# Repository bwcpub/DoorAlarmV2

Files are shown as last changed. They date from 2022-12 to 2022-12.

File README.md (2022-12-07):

# DoorAlarmV2

## A newer, hopefully better, version of the Door Alarm board.

**(C) 2022 Ben Cantrick. These files are distributed under a Creative Commons Attribution-ShareAlike license, see LICENSE_CCBYSA40.TXT.**

A newer, hopefully better, version of the Door Alarm board. Now fully compliant with the "just use a 555 timer" meme!

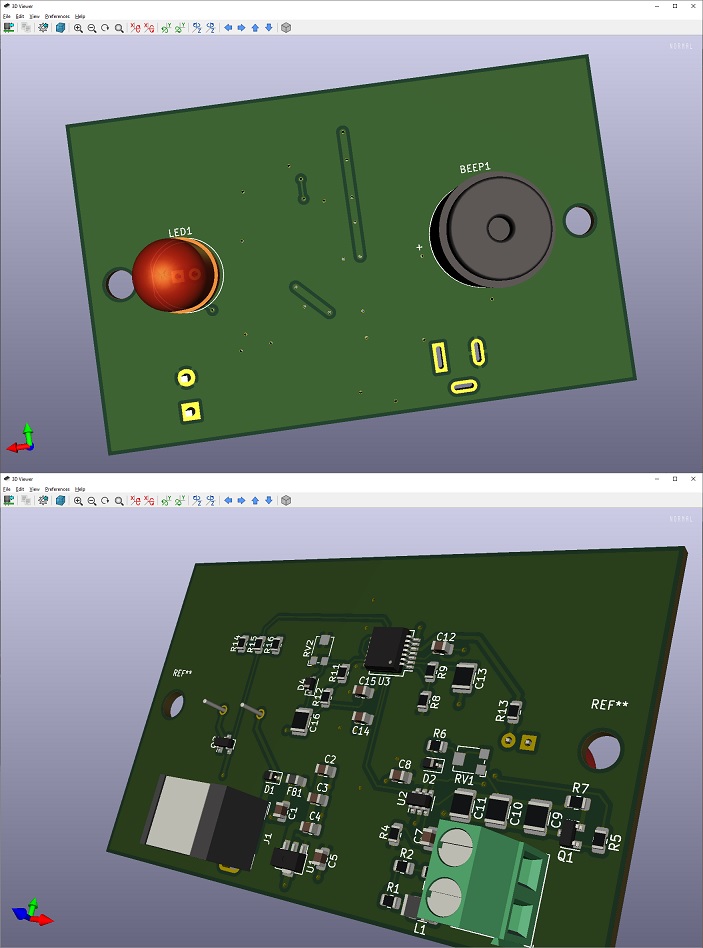
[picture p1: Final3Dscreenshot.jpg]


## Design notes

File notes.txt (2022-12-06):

Fits in a single gang electrical box.
Nominal width: 2 in = 50.8mm
Nominal height: 4 in = 101.6mm (see below)
Nominal depth: 1 7/8 in = 1.875 in = 47.625mm

Two inside flanges for attaching top plate reduce height by ~10mm each, so usable height more like 80mm.

PCB size target: 80mm x 50mm

-----

Simulation: See "falstadsim circuit.txt"

-----

https://www.digikey.com/en/products/detail/taiyo-yuden/LMK325B7476KM-PR/5810977

47 uF X7R 10V 1210 ceramic cap, 3 in parallel for 141 uF (+ 562k 1% resistor = 61s to charge from 0 to 2.7V from a 5V regulated source)
Manuf renamed part to MSASL32MSB7476KPNB25_RS sometime in late 2021.
Manuf data sheet claims 100MOhm per uF for insulation resistance. That would make parallel of three = 4.7 GOhm / 3 = ~1.56 GOhm.

-----

Dual schmitt buffer, $0.33 @10 (not in-stock at Digikey)
Mouser # 595-SN74LVC2G17DBVT

32 mA max output drive at Vcc=4.5V  (full device limited to 50mA total, so keep each output to ~20mA)

Data sheet says bypass with 0.1 uF cap as close as possible to VCC. (Multiple parallel caps OK if desired.)

TI "DBV00006A" package legs are nearly identical to SOT-23-6 footprint. (Case is very slightly larger.)

-------

10mm Red LED
https://www.mouser.com/ProductDetail/Kingbright/WP813SRD-E?qs=58z0TXQGVSToOd55Z46ELQ%3D%3D

-----

Buzzer - nice balance of cost vs loudness. $2.80 @10
https://www.digikey.com/en/products/detail/cui-devices/CMI-1614C-120/6012412

556 timer 
https://www.digikey.com/en/products/detail/texas-instruments/NE556DBR/1571972

PNP
https://www.digikey.com/en/products/detail/diodes-incorporated/MMBT3906-7-F/770797

-----

10k trim pot for beep duration - https://www.digikey.com/en/products/detail/bourns-inc/TC33X-2-103E/612858

500k trim pot for door open to alarm delay - https://www.digikey.com/en/products/detail/bourns-inc/TC33X-2-504E/2566902

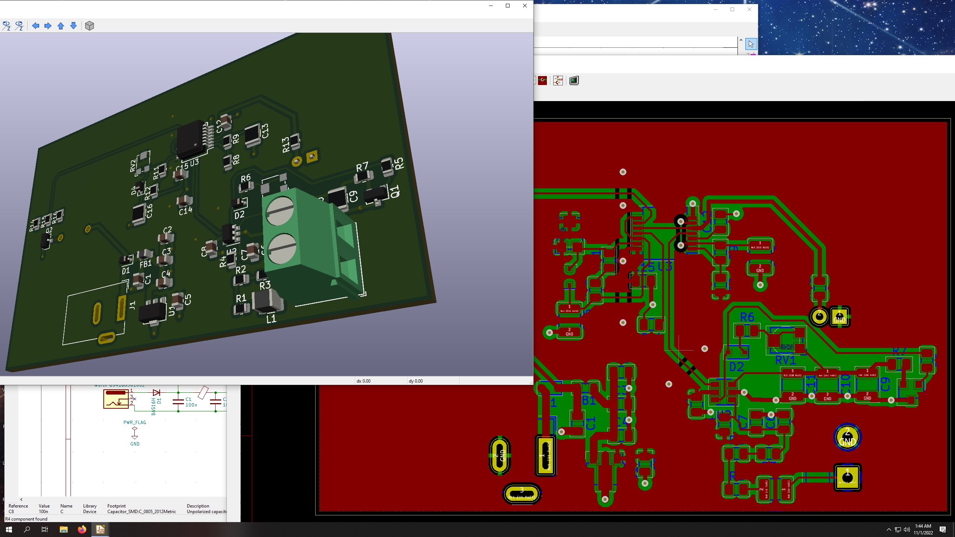
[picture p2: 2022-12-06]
WIPscreenshot.jpg

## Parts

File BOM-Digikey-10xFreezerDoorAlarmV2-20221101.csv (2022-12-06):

Country of Origin may be different at time of shipment.
The HTSUS and ECCN information shown is for informational purposes only and is not a representation or warranty as to the accuracy or reliability of these classifications. All information is provided "as is" and is subject to change without notice. Any use made of the information provided is without recourse to Digi-Key and at the user's risk.
Index | Manufacturer Part Number | Manufacturer Name | Description | Availability | Stock Status | Attrition % | Requested Quantity 1 | Pack Quantity 1 | Pack Type 1 | Digi-Key Part Number 1 | Unit Price 1 | Extended Price 1 | Minimum Order Quantity 1 | Customer Reference | Requested Part Number | Lead Weeks | Datasheet | Reference Designator | US Import Tariff | Note | Part Status | RoHS Status | ECCN | HTSUS | Country of Origin | Environmental Information | Original Part numbers | Image
1 | CMI-1614C-120 | CUI Devices | BUZZER MAGNETIC 12V 16MM TH | 239 | In Stock |  | 10 | 10 | Tray | 102-3741-ND | 2.79100 | $27.91 | 1 |  | 102-3741-ND | 8 | https://www.cuidevices.com/product/resource/cmi-1614c-120.pdf |  | May apply on shipments to the U.S. |  | Active | ROHS3 Compliant | EAR99 | 8531.80.9041 | China | https://www.cuidevices.com/product/resource/material-compliance/cmi-1614c-120 | 102-3741-ND | https://media.digikey.com/photos/CUI%20Photos/MFG_CMI-1614C-120.jpg
2 | 1729128 | Phoenix Contact | TERM BLK 2P SIDE ENT 5.08MM PCB | 39,675 | In Stock |  | 10 | 10 | Bulk | 277-1247-ND | 1.16200 | $11.62 | 1 |  | 277-1247-ND | 21 | https://www.phoenixcontact.com/product/pdf/MTcyOTEyOA?_realm=us&_locale=en-US |  | May apply on shipments to the U.S. |  | Active | ROHS3 Compliant | EAR99 | 8536.69.4040 | China | https://www.phoenixcontact.com/online/portal/us?1dmy | 277-1247-ND | https://media.digikey.com/photos/Phoenix%20Photos/1729128.jpg
3 | 694106301002 | Würth Elektronik | CONN PWR JACK 2.1X5.5MM SOLDER | 40,477 | In Stock |  | 10 | 10 | Bag | 732-5930-ND | 0.97000 | $9.70 | 1 |  | 732-5930-ND | 15 | https://www.we-online.com/katalog/datasheet/6941xx301002.pdf |  | May apply on shipments to the U.S. |  | Active | ROHS3 Compliant | EAR99 | 8536.69.4040 | China | https://media.digikey.com/pdf/Other%20Related%20Documents/Wurth/Certificate_of_Compliance_ROHS.pdf | 732-5930-ND | https://media.digikey.com/Photos/Wurth%20Electronics%20Photos/MFG_694106x0x002.jpg
4 | WLBD2012HCU601TH | Walsin Technology Corporation | CHIP BEAD 600 OHM 0805 | 2,823 | In Stock |  | 10 | 10 | Cut Tape (CT) | 1292-WLBD2012HCU601THCT-ND | 0.02800 | $0.28 | 1 |  | 1292-WLBD2012HCU601THCT-ND | 30 | http://www.passivecomponent.com/wp-content/uploads/inductor/WLBD1005-4532_HC_Series.pdf |  | - |  | Active | ROHS3 Compliant | EAR99 | 8548.00.0000 | Taiwan | http://www.passivecomponent.com/download/reach_rohs_compliance_declaration-2/?wpdmdl=1343 | 1292-WLBD2012HCU601THCT-ND | https://media.digikey.com/Renders/Walsin%20Tech/WLBD2012x.JPG
5 | NE556DBR | Texas Instruments | IC OSC TIMER DUAL 100KHZ 14SSOP | 505 | In Stock |  | 10 | 10 | Cut Tape (CT) | 296-31698-1-ND | 0.49700 | $4.97 | 1 |  | 296-31698-1-ND | 6 | https://www.ti.com/general/docs/suppproductinfo.tsp?distId=10 |  | - |  | Active | ROHS3 Compliant | EAR99 | 8542.39.0001 | Malaysia |  | 296-31698-1-ND | https://media.digikey.com/photos/Texas%20Instr%20Photos/296-14-SSOP.jpg
6 | AS78L05RTR-E1 | Diodes Incorporated | IC REG LINEAR 5V 100MA SOT89-3 | 220,818 | In Stock |  | 10 | 10 | Cut Tape (CT) | AS78L05RTR-E1DICT-ND | 0.30600 | $3.06 | 1 |  | AS78L05RTR-E1DICT-ND | 27 | https://media.digikey.com/pdf/Data%20Sheets/Diodes%20PDFs/AS78Lxx_Aug2013_DS.pdf |  | May apply on shipments to the U.S. |  | Active | ROHS3 Compliant | EAR99 | 8542.39.0001 | China | https://www.diodes.com/assets/Quality-Reliability-Docs/Master_CofC.pdf | AS78L05RTR-E1DICT-ND | https://media.digikey.com/Renders/Diodes%20Renders/SOT89-3L.jpg
7 | TC33X-2-103E | Bourns Inc. | TRIMMER 10K OHM 0.1W J LEAD TOP | 113,212 | In Stock |  | 10 | 10 | Cut Tape (CT) | TC33X-103ECT-ND | 0.27300 | $2.73 | 1 |  | TC33X-103ECT-ND | 32 | https://www.bourns.com/docs/Product-Datasheets/TC33.pdf |  | May apply on shipments to the U.S. |  | Active | ROHS3 Compliant | EAR99 | 8533.40.8050 | China | https://www.bourns.com/docs/rohs-cofc/cofc_trim2.pdf?sfvrsn=d03d9c0f_4|https://www.bourns.com/docs/rohs-content/bourns-reach-letter.pdf | TC33X-103ECT-ND | https://media.digikey.com/photos/Bourns%20Photos/TC33X%20SERIES.jpg
8 | TC33X-2-504E | Bourns Inc. | TRIMMER 500K OHM 0.1W J LEAD TOP | 3,746 | In Stock |  | 10 | 10 | Cut Tape (CT) | TC33X-2-504ECT-ND | 0.27300 | $2.73 | 1 |  | TC33X-2-504ECT-ND | 32 | https://www.bourns.com/docs/Product-Datasheets/TC33.pdf |  | May apply on shipments to the U.S. |  | Active | ROHS3 Compliant | EAR99 | 8533.40.8050 | China | https://www.bourns.com/docs/rohs-content/bourns-reach-letter.pdf|https://www.bourns.com/docs/rohs-cofc/cofc_trim2.pdf?sfvrsn=d03d9c0f_4 | TC33X-2-504ECT-ND | https://media.digikey.com/photos/Bourns%20Photos/TC33X%20SERIES.jpg
9 | NVTR4503NT1G | onsemi | MOSFET N-CH 30V 1.5A SOT23-3 | 11,318 | In Stock |  | 10 | 10 | Cut Tape (CT) | NVTR4503NT1GOSCT-ND | 0.30600 | $3.06 | 1 |  | NVTR4503NT1GOSCT-ND | 48 | https://www.onsemi.com/pdf/datasheet/ntr4503n-d.pdf |  | May apply on shipments to the U.S. |  | Active | ROHS3 Compliant | EAR99 | 8541.21.0095 | China | https://www.onsemi.com/site/pdf/RoHS-statement.pdf|https://www.onsemi.com/PowerSolutions/MaterialComposition.do?export=pdf&opnId=NVTR4503NT1G|https://www.onsemi.com/site/pdf/REACH-compliance-statement.pdf | NVTR4503NT1GOSCT-ND | https://media.digikey.com/Renders/On%20Semi%20Renders/SOT-23-3,TO-236-3,Micro3,SSD3,SST3.jpg
10 | MMBT3906-7-F | Diodes Incorporated | TRANS PNP 40V 0.2A SOT23-3 | 463,784 | In Stock |  | 10 | 10 | Cut Tape (CT) | MMBT3906-FDICT-ND | 0.11700 | $1.17 | 1 |  | MMBT3906-FDICT-ND | 26 | https://media.digikey.com/pdf/Data%20Sheets/Diodes%20PDFs/MMBT3906.pdf |  | May apply on shipments to the U.S. |  | Active | ROHS3 Compliant | EAR99 | 8541.21.0075 | China | https://www.diodes.com/assets/Quality-Reliability-Docs/Master_CofC.pdf | MMBT3906-FDICT-ND | https://media.digikey.com/Photos/Diodes%20Photos/SOT-23-3%20PKG.jpg
11 | BAS16HT3G | onsemi | DIODE GEN PURP 100V 200MA SOD323 | 78,000 | In Stock |  | 30 | 30 | Cut Tape (CT) | BAS16HT3GOSCT-ND | 0.11700 | $3.51 | 1 |  | BAS16HT3GOSCT-ND | 59 | https://www.onsemi.com/pdf/datasheet/bas16ht1-d.pdf |  | May apply on shipments to the U.S. |  | Active | ROHS3 Compliant | EAR99 | 8541.10.0070 | China | https://www.onsemi.com/site/pdf/RoHS-statement.pdf|https://www.onsemi.com/PowerSolutions/MaterialComposition.do?export=pdf&opnId=BAS16HT3G|https://www.onsemi.com/site/pdf/REACH-compliance-statement.pdf | BAS16HT3GOSCT-ND | https://media.digikey.com/Renders/On%20Semi%20Renders/SOD-323_477.jpg
12 | LB3218T102K | Taiyo Yuden | FIXED IND 1MH 39MA 27 OHM SMD | 86,463 | In Stock |  | 10 | 10 | Cut Tape (CT) | 587-2041-1-ND | 0.14600 | $1.46 | 1 |  | 587-2041-1-ND | 35 | https://ds.yuden.co.jp/TYCOMPAS/ut/detail?pn=LB3218T102K &u=M |  | - |  | Active | ROHS3 Compliant | EAR99 | 8504.50.8000 | Philippines |  | 587-2041-1-ND | https://media.digikey.com/Photos/Taiyo%20Yuden%20Photos/MFG_LB3218T681KV.jpg
13 | LMK325B7476KM-PR | Taiyo Yuden | CAP CER 47UF 10V X7R 1210 | 94,515 | In Stock |  | 50 | 50 | Cut Tape (CT) | 587-5921-1-ND | 0.52240 | $26.12 | 1 |  | 587-5921-1-ND | 56 | https://www.yuden.co.jp/productdata/catalog/mlcc06_e.pdf |  | - |  | Active | ROHS3 Compliant | EAR99 | 8532.24.0020 | South Korea |  | 587-5921-1-ND | https://media.digikey.com/Renders/Taiyo%20Yuden%20Renders/1210-(3225-Metric)-2,70mm.jpg
14 | CL21B104MACNNNC | Samsung Electro-Mechanics | CAP CER 0.1UF 25V X7R 0805 | 503,335 | In Stock |  | 100 | 100 | Cut Tape (CT) | 1276-2449-1-ND | 0.01240 | $1.24 | 1 |  | 1276-2449-1-ND | 22 | http://www.samsungsem.com/kr/support/product-search/mlcc/CL21B104MACNNNC.jsp |  | - |  | Active | ROHS3 Compliant | EAR99 | 8532.24.0020 | China | https://www.samsungsem.com/global/support/certificate/product-stewardship.do|https://www.samsungsem.com/files/fileDown.do?key=ed1dfdfa-645e-4252-b707-17f9b1502dd1 | 1276-2449-1-ND | https://media.digikey.com/Renders/Samsung%20Electro-Mechanics%20America/Ceramic-Capacitor-CL-Series.jpg
15 | RMCF0805FT62K0 | Stackpole Electronics Inc | RES 62K OHM 1% 1/8W 0805 | 58,468 | In Stock |  | 10 | 10 | Cut Tape (CT) | RMCF0805FT62K0CT-ND | 0.02400 | $0.24 | 1 |  | RMCF0805FT62K0CT-ND | 15 | https://www.seielect.com/catalog/sei-rmcf_rmcp.pdf |  | May apply on shipments to the U.S. |  | Active | ROHS3 Compliant | EAR99 | 8533.21.0030 | Taiwan | https://www.seielect.com/catalog/reach.pdf|https://www.seielect.com/catalog/cert-of-compliance.pdf|https://www.seielect.com/catalog/SEI-RoHS_Compliance_Status.pdf | RMCF0805FT62K0CT-ND | https://media.digikey.com/Renders/Stackpole%20Renders/0805-RMCF-Series.jpg
16 | WR08X153 JTL | Walsin Technology Corporation | RES 15K OHM 5% 1/8W 0805 | 11,101 | In Stock |  | 20 | 20 | Cut Tape (CT) | 1292-WR08X153JTLCT-ND | 0.01500 | $0.30 | 1 |  | 1292-WR08X153JTLCT-ND | 26 | http://www.passivecomponent.com/wp-content/uploads/chipR/ASC_WR.pdf |  | May apply on shipments to the U.S. |  | Active | ROHS3 Compliant | EAR99 | 8533.21.0030 | China | http://www.passivecomponent.com/download/reach_rohs_compliance_declaration-2/?wpdmdl=1343 | 1292-WR08X153JTLCT-ND | https://media.digikey.com/Renders/Stackpole%20Renders/0201-RMCF-Series.jpg
17 | RMCF0805JT8K20 | Stackpole Electronics Inc | RES 8.2K OHM 5% 1/8W 0805 | 128,993 | In Stock |  | 10 | 10 | Cut Tape (CT) | RMCF0805JT8K20CT-ND | 0.01800 | $0.18 | 1 |  | RMCF0805JT8K20CT-ND | 15 | https://www.seielect.com/catalog/sei-rmcf_rmcp.pdf |  | - |  | Active | ROHS3 Compliant | EAR99 | 8533.21.0030 | China | https://www.seielect.com/catalog/cert-of-compliance.pdf|https://www.seielect.com/catalog/SEI-RoHS_Compliance_Status.pdf|https://www.seielect.com/catalog/reach.pdf | RMCF0805JT8K20CT-ND | https://media.digikey.com/Renders/Stackpole%20Renders/0805-RMCF-Series.jpg
18 | RMCF0805FT1K00 | Stackpole Electronics Inc | RES 1K OHM 1% 1/8W 0805 | 3,216,460 | In Stock |  | 30 | 30 | Cut Tape (CT) | RMCF0805FT1K00CT-ND | 0.02400 | $0.72 | 1 |  | RMCF0805FT1K00CT-ND | 15 | https://www.seielect.com/catalog/sei-rmcf_rmcp.pdf |  | May apply on shipments to the U.S. |  | Active | ROHS3 Compliant | EAR99 | 8533.21.0030 | China | https://www.seielect.com/catalog/reach.pdf|https://www.seielect.com/catalog/SEI-RoHS_Compliance_Status.pdf|https://www.seielect.com/catalog/cert-of-compliance.pdf | RMCF0805FT1K00CT-ND | https://media.digikey.com/Renders/Stackpole%20Renders/0805-RMCF-Series.jpg
19 | RMCF0805JT120R | Stackpole Electronics Inc | RES 120 OHM 5% 1/8W 0805 | 132,603 | In Stock |  | 100 | 100 | Cut Tape (CT) | RMCF0805JT120RCT-ND | 0.00730 | $0.73 | 1 |  | RMCF0805JT120RCT-ND | 15 | https://www.seielect.com/catalog/sei-rmcf_rmcp.pdf |  | May apply on shipments to the U.S. |  | Active | ROHS3 Compliant | EAR99 | 8533.21.0030 | Taiwan | https://www.seielect.com/catalog/cert-of-compliance.pdf|https://www.seielect.com/catalog/SEI-RoHS_Compliance_Status.pdf|https://www.seielect.com/catalog/reach.pdf | RMCF0805JT120RCT-ND | https://media.digikey.com/Renders/Stackpole%20Renders/0805-RMCF-Series.jpg
20 | RMCF0805JT12R0 | Stackpole Electronics Inc | RES 12 OHM 5% 1/8W 0805 | 4,677 | In Stock |  | 20 | 20 | Cut Tape (CT) | RMCF0805JT12R0CT-ND | 0.01800 | $0.36 | 1 |  | RMCF0805JT12R0CT-ND | 15 | https://www.seielect.com/catalog/sei-rmcf_rmcp.pdf |  | May apply on shipments to the U.S. |  | Active | ROHS3 Compliant | EAR99 | 8533.21.0030 | China | https://www.seielect.com/catalog/reach.pdf|https://www.seielect.com/catalog/cert-of-compliance.pdf|https://www.seielect.com/catalog/SEI-RoHS_Compliance_Status.pdf | RMCF0805JT12R0CT-ND | https://media.digikey.com/Renders/Stackpole%20Renders/0805-RMCF-Series.jpg
21 | 341 | Keystone Electronics | WASHER SHOULDER #6 NYLON | 9,009 | In Stock |  | 25 | 25 | Bulk | 36-341-ND | 0.15240 | $3.81 | 1 |  | 36-341-ND | 20 | https://www.keyelco.com/userAssets/file/M65p137.pdf |  | - |  | Active | ROHS3 Compliant | EAR99 | 3926.90.4590 | United States | https://www.keyelco.com/userAssets/file/RoHS_Statement.pdf|https://www.keyelco.com/userAssets/file/reach.pdf | 36-341-ND | https://media.digikey.com/photos/Keystone%20Elect%20Photos/341.JPG
22 | 9905 | Keystone Electronics | MACHINE SCREW PAN PHILLIPS 6-32 | 12,415 | In Stock |  | 25 | 25 | Bulk | 36-9905-ND | 0.11400 | $2.85 | 1 |  | 36-9905-ND | 20 | https://www.keyelco.com/userAssets/file/M65p91.pdf |  | May apply on shipments to the U.S. |  | Active | ROHS3 Compliant | EAR99 | 7318.15.6040 | China | https://www.keyelco.com/userAssets/file/reach.pdf|https://www.keyelco.com/userAssets/file/RoHS_Statement.pdf | 36-9905-ND | https://media.digikey.com/Photos/Keystone%20Elect%20Photos/MFG_99xy.jpg
23 | 9912-125 | Bivar Inc. | ROUND SPACER #8 NYLON 1/8" | 12,990 | In Stock |  | 25 | 25 | Bulk | 492-1117-ND | 0.04040 | $1.01 | 1 |  | 492-1117-ND | 10 | https://www.bivar.com/parts_content/Datasheets/99XX-XXX.pdf |  | - |  | Active | ROHS3 Compliant | EAR99 | 3926.90.9985 | United States | https://www.bivar.com/part_content/rohs/?9912-125 | 492-1117-ND | https://media.digikey.com/photos/Bivar%20Inc%20Photos/9912-125.jpg

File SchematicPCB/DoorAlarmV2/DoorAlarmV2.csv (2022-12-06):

Reference | Value | Footprint | Datasheet | AVAILABILITY | DESCRIPTION | MF | MP | PACKAGE | PRICE
J1 | Würth 694106301002 |  | https://www.we-online.com/katalog/datasheet/6941xx301002.pdf
D1 | BAS16H | Diode_SMD:D_SOD-323 | https://www.onsemi.com/pdf/datasheet/bas16ht1-d.pdf
FB1 | WLBD2012HCU601TH |  | http://www.passivecomponent.com/wp-content/uploads/inductor/WLBD1005-4532_HC_Series.pdf
C1 | 100n | Capacitor_SMD:C_0805_2012Metric | http://www.samsungsem.com/kr/support/product-search/mlcc/CL21B104MACNNNC.jsp
C2 | 100n | Capacitor_SMD:C_0805_2012Metric | http://www.samsungsem.com/kr/support/product-search/mlcc/CL21B104MACNNNC.jsp
C3 | 100n | Capacitor_SMD:C_0805_2012Metric | http://www.samsungsem.com/kr/support/product-search/mlcc/CL21B104MACNNNC.jsp
C4 | 100n | Capacitor_SMD:C_0805_2012Metric | http://www.samsungsem.com/kr/support/product-search/mlcc/CL21B104MACNNNC.jsp
U1 | AS78L05R | Package_TO_SOT_SMD:SOT-89-3 | https://media.digikey.com/pdf/Data%20Sheets/Diodes%20PDFs/AS78Lxx_Aug2013_DS.pdf
C5 | 100n | Capacitor_SMD:C_0805_2012Metric | http://www.samsungsem.com/kr/support/product-search/mlcc/CL21B104MACNNNC.jsp
J2 | Phoenix #1729128 | TerminalBlock_Phoenix:TerminalBlock_Phoenix_MKDS-1,5-2-5.08_1x02_P5.08mm_Horizontal | https://www.phoenixcontact.com/product/pdf/MTcyOTEyOA?_realm=us&_locale=en-US
L1 | 1000 uH | Inductor_SMD:L_1210_3225Metric | https://ds.yuden.co.jp/TYCOMPAS/ut/detail?pn=LB3218T102K%20%20&u=M
R1 | 1k | Resistor_SMD:R_0805_2012Metric | https://www.seielect.com/catalog/sei-rmcf_rmcp.pdf
R2 | 120 | Resistor_SMD:R_0805_2012Metric | https://www.seielect.com/catalog/sei-rmcf_rmcp.pdf
R3 | 120 | Resistor_SMD:R_0805_2012Metric | https://www.seielect.com/catalog/sei-rmcf_rmcp.pdf
C6 | 100n | Capacitor_SMD:C_0805_2012Metric | http://www.samsungsem.com/kr/support/product-search/mlcc/CL21B104MACNNNC.jsp
C7 | 100n | Capacitor_SMD:C_0805_2012Metric | http://www.samsungsem.com/kr/support/product-search/mlcc/CL21B104MACNNNC.jsp
R4 | 8.2k | Resistor_SMD:R_0805_2012Metric | https://www.seielect.com/catalog/sei-rmcf_rmcp.pdf
U2 | 74LVC2G17 | Package_TO_SOT_SMD:SOT-23-6 | http://www.ti.com/lit/sg/scyt129e/scyt129e.pdf
C8 | 100n | Capacitor_SMD:C_0805_2012Metric | http://www.samsungsem.com/kr/support/product-search/mlcc/CL21B104MACNNNC.jsp
C9 | 47u | Resistor_SMD:R_1210_3225Metric | https://www.yuden.co.jp/productdata/catalog/mlcc06_e.pdf
C10 | 47u | Resistor_SMD:R_1210_3225Metric | https://www.yuden.co.jp/productdata/catalog/mlcc06_e.pdf
C11 | 47u | Resistor_SMD:R_1210_3225Metric | https://www.yuden.co.jp/productdata/catalog/mlcc06_e.pdf
D2 | BAS16H | Diode_SMD:D_SOD-323 | https://www.onsemi.com/pdf/datasheet/bas16ht1-d.pdf
R6 | 62k | Resistor_SMD:R_0805_2012Metric | https://www.seielect.com/catalog/sei-rmcf_rmcp.pdf
R7 | 12 | Resistor_SMD:R_0805_2012Metric | https://www.seielect.com/catalog/sei-rmcf_rmcp.pdf
R5 | 120 | Resistor_SMD:R_0805_2012Metric | https://www.seielect.com/catalog/sei-rmcf_rmcp.pdf
Q1 | MMBT3906 | Package_TO_SOT_SMD:SOT-23 | https://media.digikey.com/pdf/Data%20Sheets/Diodes%20PDFs/MMBT3906.pdf
RV1 | 500k | Potentiometer_SMD:Potentiometer_Bourns_TC33X_Vertical | https://www.bourns.com/docs/Product-Datasheets/TC33.pdf
U3 | NA556 |  | http://www.ti.com/lit/ds/symlink/se556.pdf
C12 | 100n | Capacitor_SMD:C_0805_2012Metric | http://www.samsungsem.com/kr/support/product-search/mlcc/CL21B104MACNNNC.jsp
C14 | 100n | Capacitor_SMD:C_0805_2012Metric | http://www.samsungsem.com/kr/support/product-search/mlcc/CL21B104MACNNNC.jsp
C15 | 100n | Capacitor_SMD:C_0805_2012Metric | http://www.samsungsem.com/kr/support/product-search/mlcc/CL21B104MACNNNC.jsp
C13 | 47u | Resistor_SMD:R_1210_3225Metric | https://www.yuden.co.jp/productdata/catalog/mlcc06_e.pdf
C16 | 47u | Resistor_SMD:R_1210_3225Metric | https://www.yuden.co.jp/productdata/catalog/mlcc06_e.pdf
R9 | 15k | Resistor_SMD:R_0805_2012Metric | https://www.seielect.com/catalog/sei-rmcf_rmcp.pdf
R8 | 1k | Resistor_SMD:R_0805_2012Metric | https://www.seielect.com/catalog/sei-rmcf_rmcp.pdf
R10 | 120 | Resistor_SMD:R_0805_2012Metric | https://www.seielect.com/catalog/sei-rmcf_rmcp.pdf
D3 | LED-Red-10mm | LED_THT:LED_D10.0mm | https://www.prtice.info/IMG/pdf/CQY99.pdf
R12 | 15k | Resistor_SMD:R_0805_2012Metric | https://www.seielect.com/catalog/sei-rmcf_rmcp.pdf
R11 | 1k | Resistor_SMD:R_0805_2012Metric | https://www.seielect.com/catalog/sei-rmcf_rmcp.pdf
D4 | BAS16H | Diode_SMD:D_SOD-323 | https://www.onsemi.com/pdf/datasheet/bas16ht1-d.pdf
RV2 | 10k | Potentiometer_SMD:Potentiometer_Bourns_TC33X_Vertical | https://www.bourns.com/docs/Product-Datasheets/TC33.pdf
Q2 | NTR4503N | Package_TO_SOT_SMD:SOT-23 | http://www.diodes.com/assets/Datasheets/BS170F.pdf
LS1 | CMI-1614C-120 | CUI_CMI-1614C-120 |  | Warning | 16 mm, 12 V, 95 dB, 2.2 kHz, Through Hole, Driving Circuit, Magnetic Audio Indicator Buzzer | CUI | CMI-1614C-120 | CUI | 2.22 USD
R14 | 120 | Resistor_SMD:R_0805_2012Metric | https://www.seielect.com/catalog/sei-rmcf_rmcp.pdf
R13 | 120 | Resistor_SMD:R_0805_2012Metric | https://www.seielect.com/catalog/sei-rmcf_rmcp.pdf
R15 | 120 | Resistor_SMD:R_0805_2012Metric | https://www.seielect.com/catalog/sei-rmcf_rmcp.pdf
R16 | 120 | Resistor_SMD:R_0805_2012Metric | https://www.seielect.com/catalog/sei-rmcf_rmcp.pdf

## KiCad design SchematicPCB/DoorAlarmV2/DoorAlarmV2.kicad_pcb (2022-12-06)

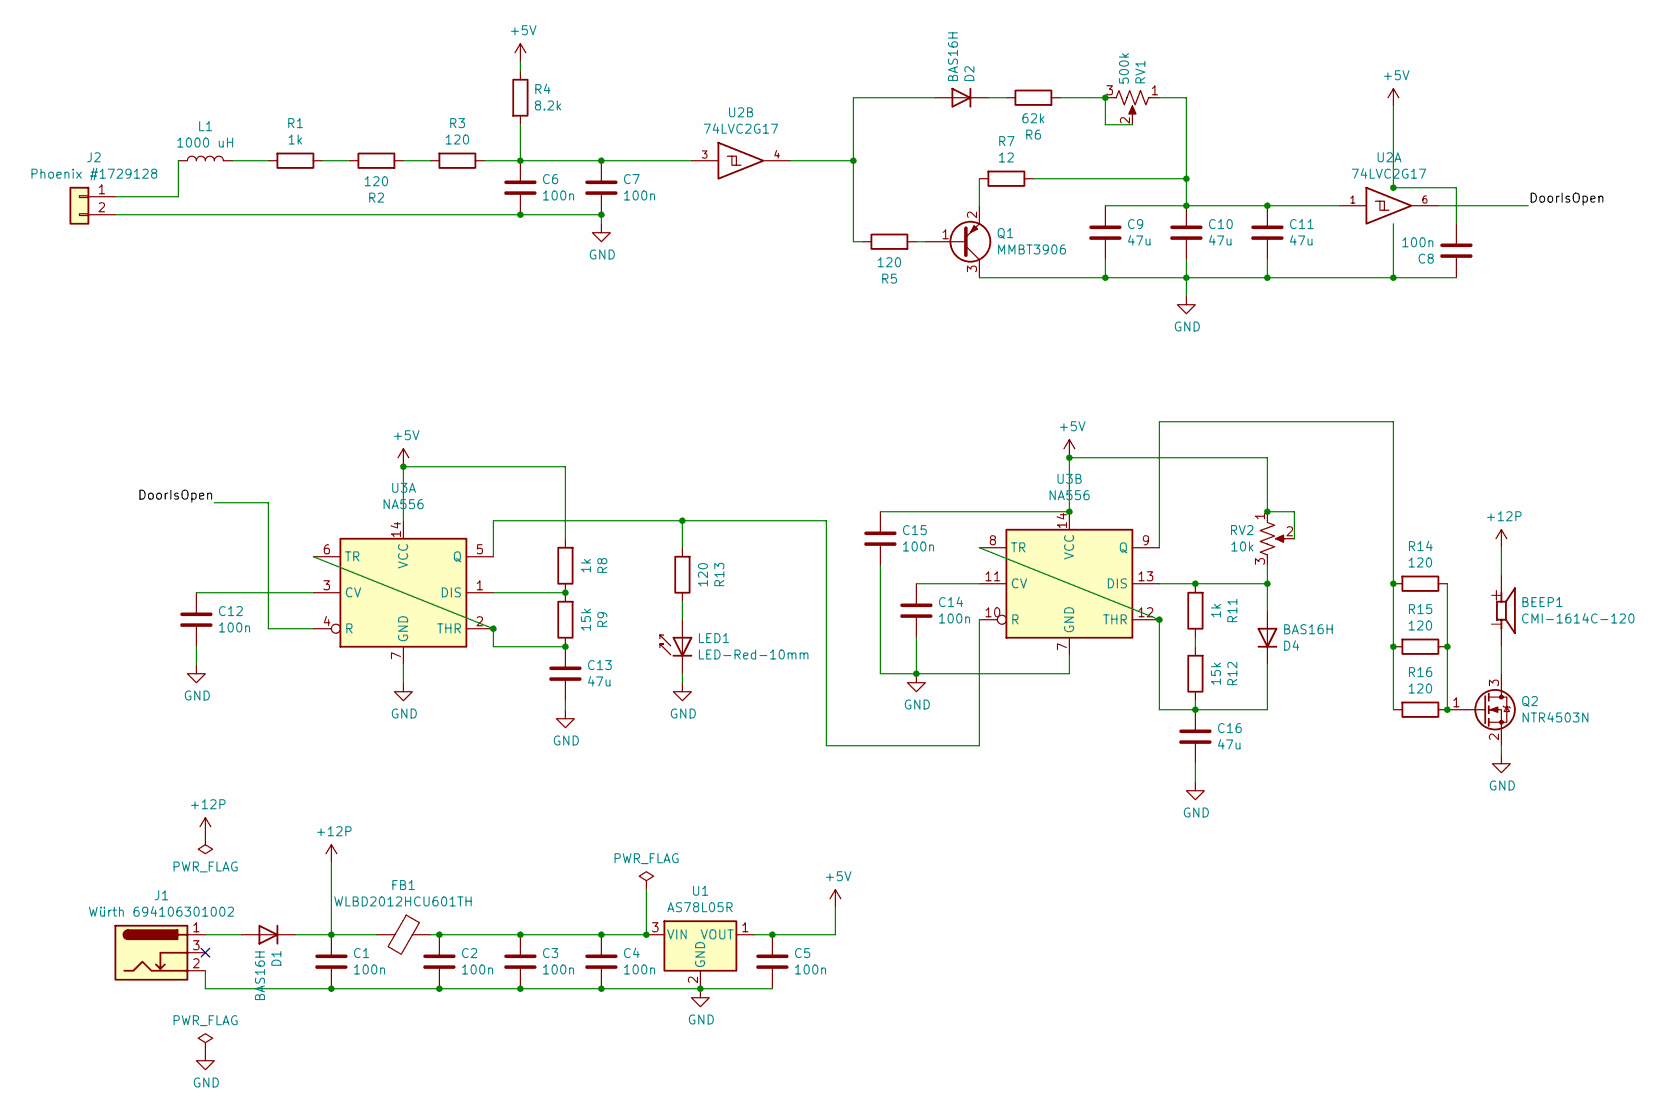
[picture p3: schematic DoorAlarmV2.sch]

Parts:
BEEP1: CMI-1614C-120; CUI_CMI-1614C-120
C1, C2, C3, C4, C5, C6, C7, C8, C12, C14, C15: 100n; C_0805_2012Metric
C9, C10, C11, C13, C16: 47u; R_1210_3225Metric
D1, D2, D4: BAS16H; D_SOD-323
FB1: WLBD2012HCU601TH; L_0805_2012Metric
J1: Würth 694106301002; BarrelJack_Wuerth_6941xx301002
J2: Phoenix #1729128; TerminalBlock_Phoenix_MKDS-1,5-2-5.08_1x02_P5.08mm_Horizont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
L1: 1000 uH; L_1210_3225Metric
LED1: LED-Red-10mm; LED_D10.0mm
Q1: MMBT3906; SOT-23
Q2: NTR4503N; SOT-23
R1, R8, R11: 1k; R_0805_2012Metric
R2, R3, R5, R13, R14, R15, R16: 120; R_0805_2012Metric
R4: 8.2k; R_0805_2012Metric
R6: 62k; R_0805_2012Metric
R7: 12; R_0805_2012Metric
R9, R12: 15k; R_0805_2012Metric
RV1: 500k; Potentiometer_Bourns_TC33X_Vertical
RV2: 10k; Potentiometer_Bourns_TC33X_Vertical
U1: AS78L05R; SOT-89-3
U2: 74LVC2G17; SOT-23-6
U3: NA556; SSOP-14_5.3x6.2mm_P0.65mm

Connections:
+5V: C5.1, C8.2, C15.1, R4.1, R8.2, RV2.1, RV2.2, U1.1 (VOUT), U2.5 (VCC), U3.14 (VCC)
+12P: BEEP1.P, C1.1, D1.1 (K), FB1.2
/DoorIsOpen: U2.6, U3.4 (R)
GND: C1.2, C2.2, C3.2, C4.2, C5.2, C6.2, C7.2, C8.1, C9.2, C10.2, C11.2, C12.2, C13.2, C14.2, C15.2, C16.2, J1.2, J2.2, LED1.1 (K), Q1.3 (C), Q2.2 (S), U1.2 (GND), U2.2 (GND), U3.7 (GND)
unnamed: BEEP1.N, Q2.3 (D)
unnamed: C2.1, C3.1, C4.1, FB1.1, U1.3 (VIN)
unnamed: C6.1, C7.1, R3.1, R4.2, U2.3
unnamed: C9.1, C10.1, C11.1, R7.1, RV1.1, U2.1
unnamed: C12.1, U3.3 (CV)
unnamed: C13.1, R9.1, U3.2 (THR), U3.6 (TR)
unnamed: C14.1, U3.11 (CV)
unnamed: C16.1, D4.1 (K), R12.1, U3.8 (TR), U3.12 (THR)
unnamed: D1.2 (A), J1.1
unnamed: D2.1 (K), R6.1
unnamed: D2.2 (A), R5.1, U2.4
unnamed: D4.2 (A), R11.2, RV2.3, U3.13 (DIS)
unnamed: J2.1, L1.1
unnamed: L1.2, R1.2
unnamed: LED1.2 (A), R13.1
unnamed: Q1.1 (B), R5.2
unnamed: Q1.2 (E), R7.2
unnamed: Q2.1 (G), R14.1, R15.1, R16.1
unnamed: R1.1, R2.1
unnamed: R2.2, R3.2
unnamed: R6.2, RV1.2, RV1.3
unnamed: R8.1, R9.2, U3.1 (DIS)
unnamed: R11.1, R12.2
unnamed: R13.2, U3.5 (Q), U3.10 (R)
unnamed: R14.2, R15.2, R16.2, U3.9 (Q)

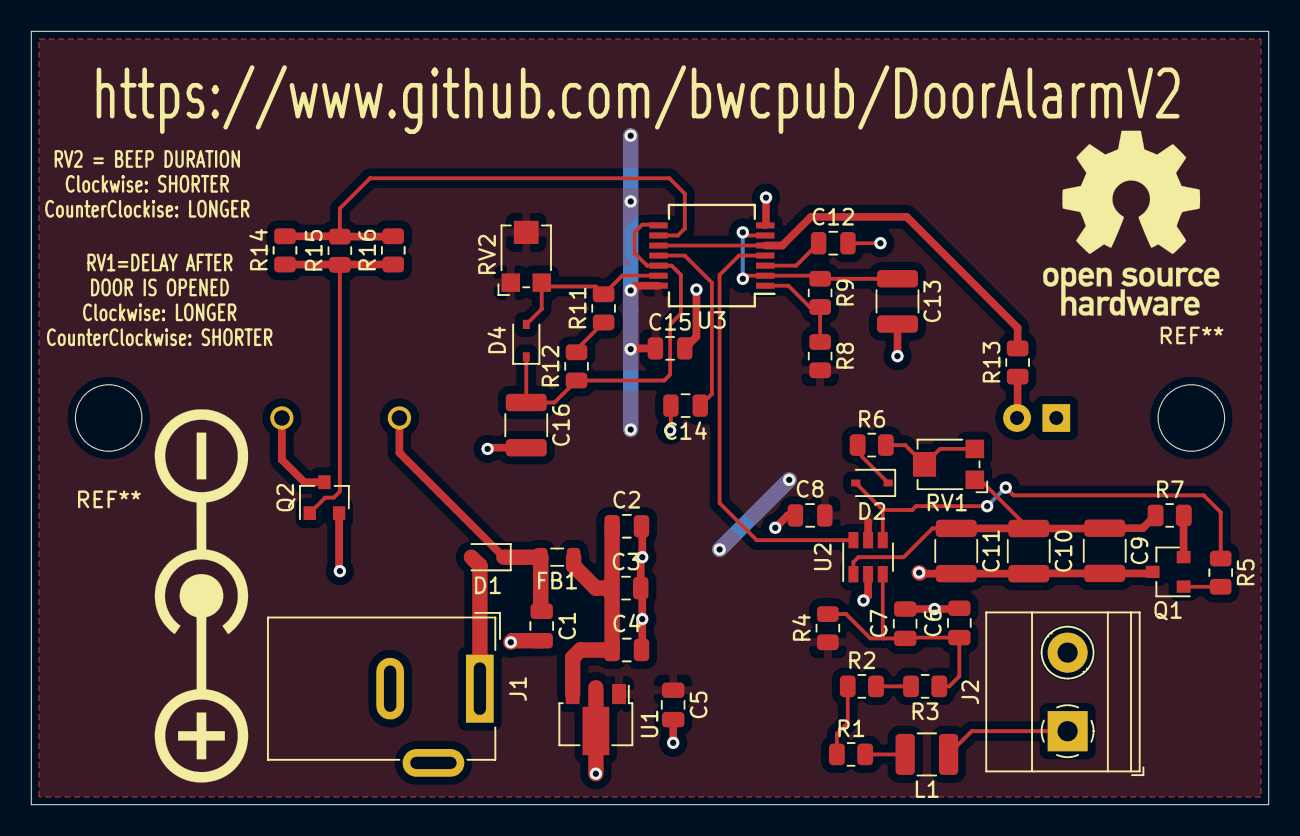
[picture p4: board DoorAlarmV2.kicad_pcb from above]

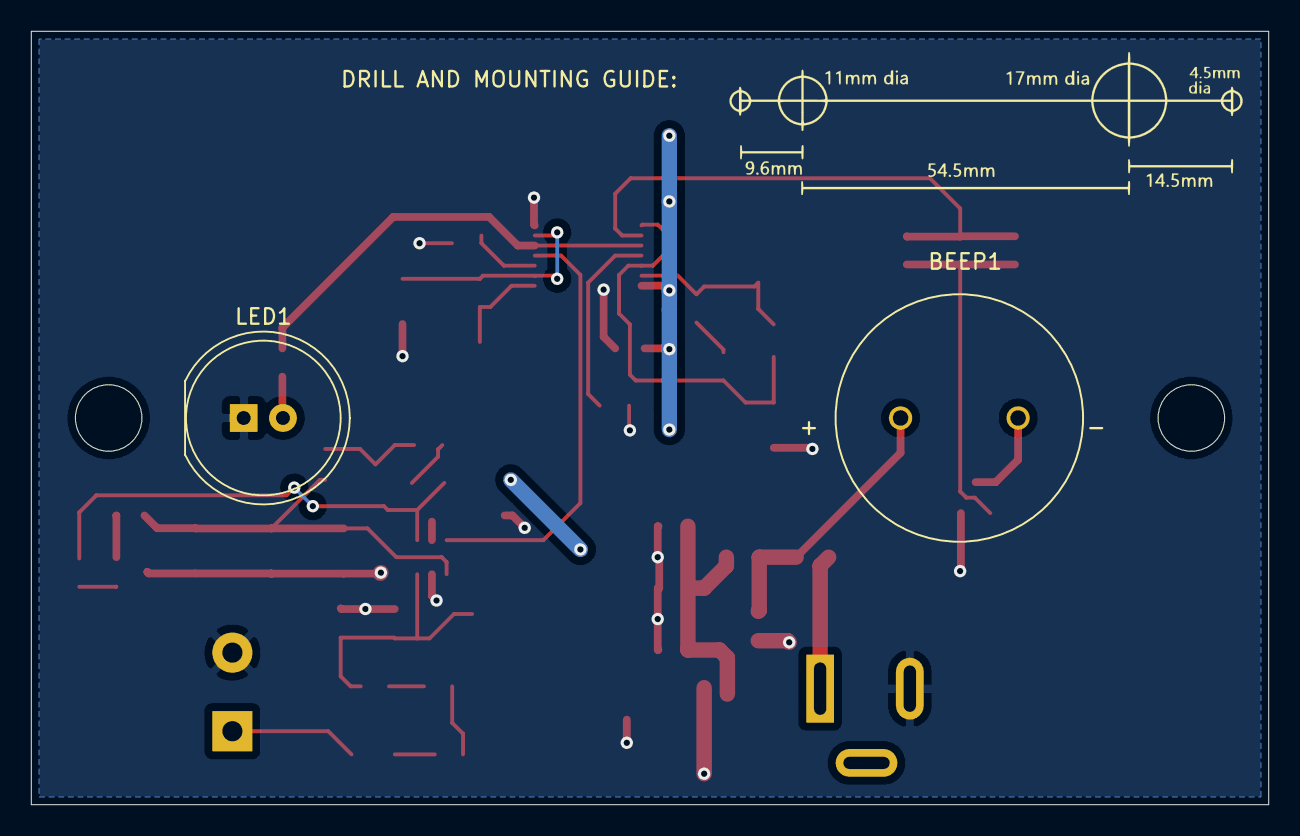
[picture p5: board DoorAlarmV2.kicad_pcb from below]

Board: 2 copper layers, 80.0 x 50.0 mm, 47 parts (2 on the bottom side), 29 nets.

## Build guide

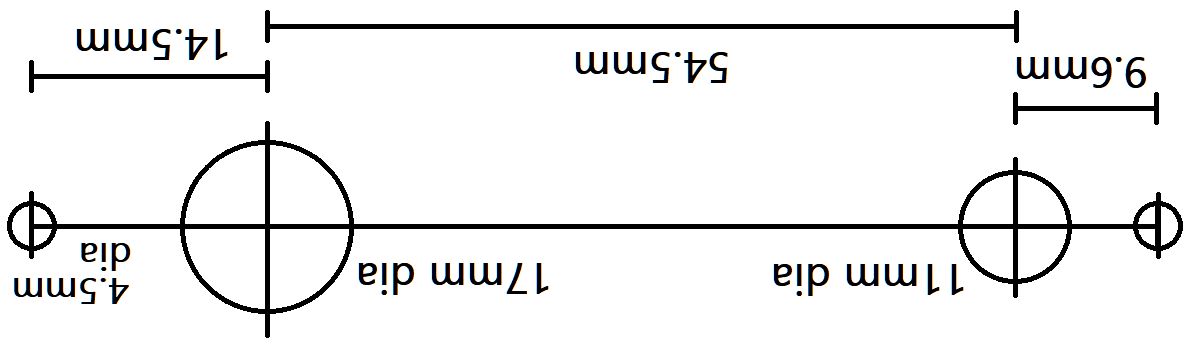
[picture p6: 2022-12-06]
SchematicPCB/DoorAlarmV2/DrillGuide.png
